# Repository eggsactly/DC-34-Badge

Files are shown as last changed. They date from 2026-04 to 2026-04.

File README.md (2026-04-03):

# About
DC-34 Badge contains the KiCad 6 design files for the Cyber Professionals 
Enthusiast Club (CPEC) DEFCON 34 Badge. 

## Board Features
- 2.2" 320x240 display
- Wifi and Bluetooth LE equiped
- 3 Shitty Add On (SAO) 1.69bis ports equiped with I2C
- Gameboy equivalent buttons
- Rumble pack

## Project Structure
The structure of this repo is organized as such:

| Directory | About |
|:---|:---|
| DC-34-Badge | KiCad 6 Design files |
| digikey-kicad-libraries | Symbol libraries and footprints downloaded from digikey |
| kicad-libraries | git subtree containing expressif design files |

## Running
To view schematics, please run KiCad 6.0.11 or later. Change directory into 
DC-34-Badge and run
```
kicad DC-34-Badge.kicad_pro
```

Please note: please run kicad from the same directory as the .kicad_pro file 
is stored because the fp-lib-table and sym-lib-table use relative paths 
so that this project is portable between computers.

# Associated Repos
Board firmware is developed in this repo: 
[https://github.com/wildcat86/DC34-Mech-Badge](https://github.com/wildcat86/DC34-Mech-Badge)

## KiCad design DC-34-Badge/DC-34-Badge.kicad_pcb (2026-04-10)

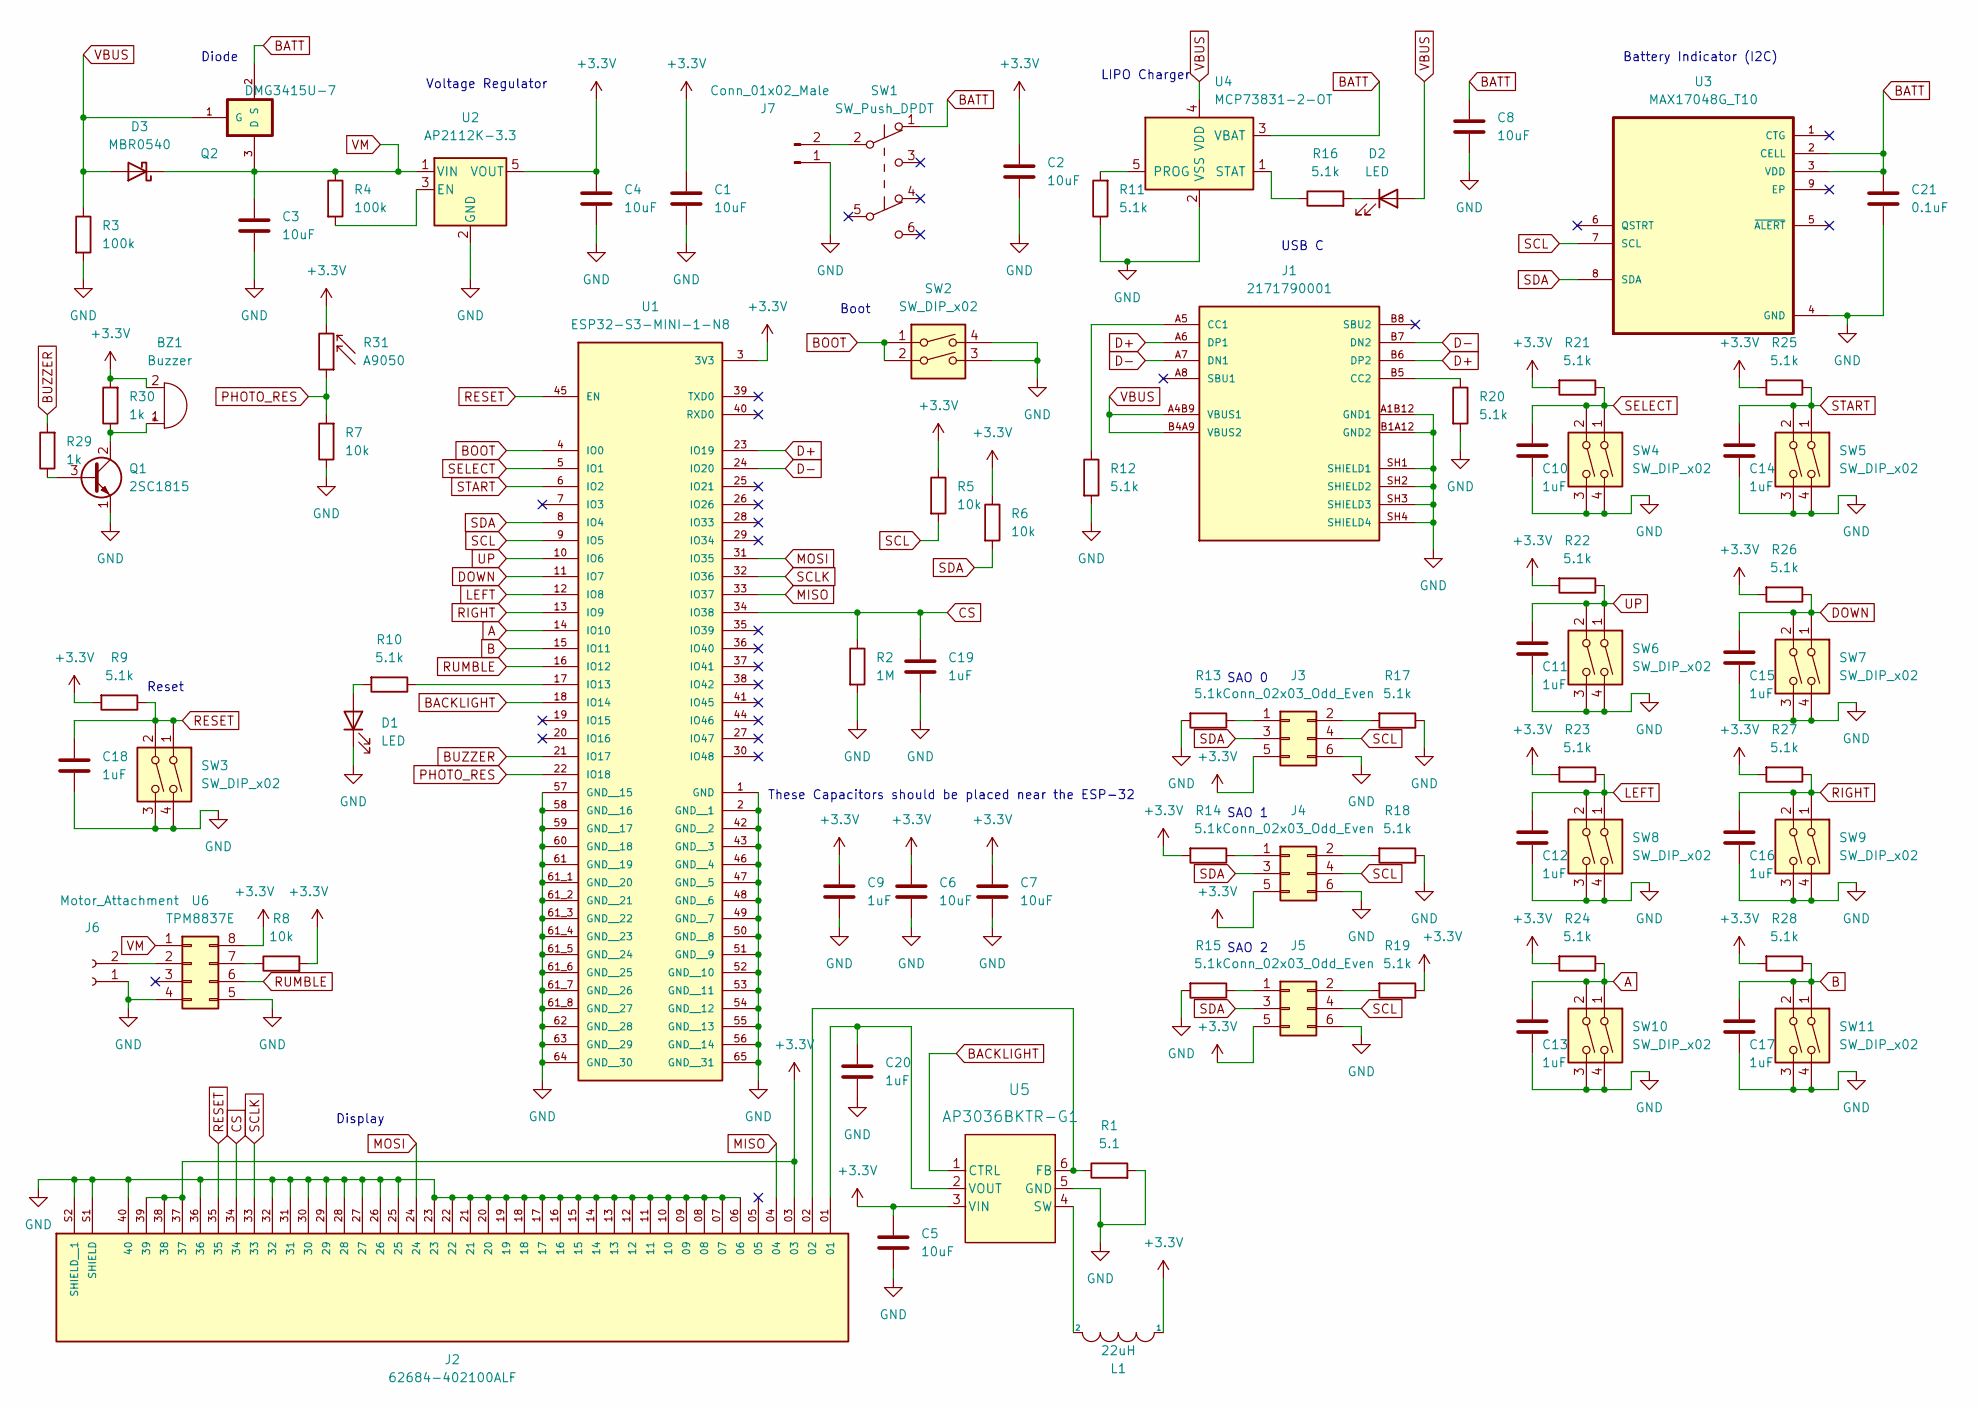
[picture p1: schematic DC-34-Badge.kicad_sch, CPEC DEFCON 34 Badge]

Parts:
BZ1: Buzzer; D_A-405_P5.08mm_Vertical_AnodeUp
C1, C2, C3, C4, C5, C6, C7, C8: 10uF; C_0402_1005Metric
C9, C10, C11, C12, C13, C14, C15, C16, C17, C18, C19, C20: 1uF; C_0402_1005Metric
C21: 0.1uF; C_0402_1005Metric
D1, D2: LED; LED_0201_0603Metric
D3: MBR0540; D_SOD-123
J1: 2171790001; MOLEX_2171790001; PARTREV A1
J2: 62684-402100ALF; AMPHENOL_62684-402100ALF; PARTREV AK
J3, J4, J5: Conn_02x03_Odd_Even; PinHeader_2x03_P2.54mm_Vertical
J6: Motor_Attachment; SolderWire-0.1sqmm_1x02_P3.6mm_D0.4mm_OD1mm
J7: Conn_01x02_Male; JST_XH_B2B-XH-AM_1x02_P2.50mm_Vertical
L1: 22uH; L_1210_3225Metric
Q1: 2SC1815; SOT-23
Q2: DMG3415U-7; SOT95P240X105-3N; MPN DMG3415U-7
R1: 5.1; R_0402_1005Metric
R2: 1M; R_0402_1005Metric
R3, R4: 100k; R_0402_1005Metric
R5, R6, R7, R8: 10k; R_0402_1005Metric
R9, R10, R11, R12, R13, R14, R15, R16, R17, R18, R19, R20, R21, R22, R23, R24, R25, R26, R27, R28: 5.1k; R_0402_1005Metric
R29, R30: 1k; R_0402_1005Metric
R31: A9050; R_LDR_5.0x4.1mm_P3mm_Vertical
SW1: SW_Push_DPDT; SW_CuK_JS202011CQN_DPDT_Straight
SW2, SW3, SW4, SW5, SW6, SW7, SW8, SW9, SW10, SW11: SW_DIP_x02; SW_PUSH_6mm
U1: ESP32-S3-MINI-1-N8; XCVR_ESP32-S3-MINI-1-N8; PARTREV v0.6
U2: AP2112K-3.3; SOT-23-5
U3: MAX17048G_T10; SON50P200X200X80-9N
U4: MCP73831-2-OT; SOT-23-5
U5: AP3036BKTR-G1; SOIC6_AP3036BKTR-G1_DIO
U6: TPM8837E; DFN-8-1EP_2x2mm_P0.5mm_EP0.8x1.6mm

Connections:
+3.3V: BZ1.2 (+), C1.1, C2.1, C4.1, C5.1, C6.1, C7.1, C9.1, J2.03, J2.37, J2.38, J2.39, J3.5, J4.5, J5.5, L1.1, R5.1, R6.1, R8.2, R9.2, R14.2, R19.1, R21.2, R22.2, R23.2, R24.2, R25.2, R26.2, R27.2, R28.2, R30.2, R31.2, U1.3 (3V3), U2.5 (VOUT), U5.3 (VIN), U6.8
A: C13.1, R24.1, SW10.1, SW10.2, U1.14 (IO10)
B: C17.1, R28.1, SW11.1, SW11.2, U1.15 (IO11)
BACKLIGHT: U1.18 (IO14), U5.1 (CTRL)
BATT: C8.1, C21.1, Q2.2 (S), SW1.1 (A), U3.2 (CELL), U3.3 (VDD), U4.3 (VBAT)
BOOT: SW2.1, SW2.2, U1.4 (IO0)
BUZZER: R29.2, U1.21 (IO17)
CS: C19.1, J2.34, R2.1, U1.34 (IO38)
D+: J1.A6 (DP1), J1.B6 (DP2), U1.23 (IO19)
D-: J1.A7 (DN1), J1.B7 (DN2), U1.24 (IO20)
DOWN: C15.1, R26.1, SW7.1, SW7.2, U1.11 (IO7)
GND: C1.2, C2.2, C3.2, C4.2, C5.2, C6.2, C7.2, C8.2, C9.2, C10.2, C11.2, C12.2, C13.2, C14.2, C15.2, C16.2, C17.2, C18.2, C19.2, C20.2, C21.2, D1.1 (K), J1.A1B12 (GND1), J1.B1A12 (GND2), J1.SH1 (SHIELD1), J1.SH2 (SHIELD2), J1.SH3 (SHIELD3), J1.SH4 (SHIELD4), J2.06, J2.07, J2.08, J2.09, J2.10, J2.11, J2.12, J2.13, J2.14, J2.15, J2.16, J2.17, J2.18, J2.19, J2.20, J2.21, J2.22, J2.23, J2.25, J2.26, J2.27, J2.28, J2.29, J2.30, J2.31, J2.32, J2.36, J2.40, J2.S1 (SHIELD), J2.S2 (SHIELD__1), J3.6, J4.6, J5.6, J6.1, J7.1, Q1.1 (E), R1.2, R2.2, R3.2, R7.1, R11.1, R12.2, R13.2, R15.2, R17.1, R18.1, R20.2, SW2.3, SW2.4, SW3.3, SW3.4, SW4.3, SW4.4, SW5.3, SW5.4, SW6.3, SW6.4, SW7.3, SW7.4, SW8.3, SW8.4, SW9.3, SW9.4, SW10.3, SW10.4, SW11.3, SW11.4, U1.1 (GND), U1.2 (GND__1), U1.42 (GND__2), U1.43 (GND__3), U1.46 (GND__4), U1.47 (GND__5), U1.48 (GND__6), U1.49 (GND__7), U1.50 (GND__8), U1.51 (GND__9), U1.52 (GND__10), U1.53 (GND__11), U1.54 (GND__12), U1.55 (GND__13), U1.56 (GND__14), U1.57 (GND__15), U1.58 (GND__16), U1.59 (GND__17), U1.60 (GND__18), U1.61 (GND__19), U1.61_1 (GND__20), U1.61_2 (GND__21), U1.61_3 (GND__22), U1.61_4 (GND__23), U1.61_5 (GND__24), U1.61_6 (GND__25), U1.61_7 (GND__26), U1.61_8 (GND__27), U1.62 (GND__28), U1.63 (GND__29), U1.64 (GND__30), U1.65 (GND__31), U2.2 (GND), U3.4 (GND), U4.2 (VSS), U5.5 (GND), U6.4, U6.5
LEFT: C12.1, R23.1, SW8.1, SW8.2, U1.12 (IO8)
MISO: J2.04, U1.33 (IO37)
MOSI: J2.24, U1.31 (IO35)
unnamed: BZ1.1 (-), Q1.2 (C), R30.1
unnamed: C20.1, J2.01, U5.2 (VOUT)
unnamed: D1.2 (A), R10.2
unnamed: D2.1 (K), R16.2
unnamed: J1.A5 (CC1), R12.1
unnamed: J1.B5 (CC2), R20.1
unnamed: J2.02, R1.1, U5.6 (FB)
unnamed: J3.1, R13.1
unnamed: J3.2, R17.2
unnamed: J4.1, R14.1
unnamed: J4.2, R18.2
unnamed: J5.1, R15.1
unnamed: J5.2, R19.2
unnamed: J6.2, U6.2
unnamed: J7.2, SW1.2 (B)
unnamed: L1.2, U5.4 (SW)
unnamed: Q1.3 (B), R29.1
unnamed: R4.2, U2.3 (EN)
unnamed: R8.1, U6.7
unnamed: R10.1, U1.17 (IO13)
unnamed: R11.2, U4.5 (PROG)
unnamed: R16.1, U4.1 (STAT)
PHOTO_RES: R7.2, R31.1, U1.22 (IO18)
RESET: C18.1, J2.35, R9.1, SW3.1, SW3.2, U1.45 (EN)
RIGHT: C16.1, R27.1, SW9.1, SW9.2, U1.13 (IO9)
RUMBLE: U1.16 (IO12), U6.6
SCL: J3.4, J4.4, J5.4, R5.2, U1.9 (IO5), U3.7 (SCL)
SCLK: J2.33, U1.32 (IO36)
SDA: J3.3, J4.3, J5.3, R6.2, U1.8 (IO4), U3.8 (SDA)
SELECT: C10.1, R21.1, SW4.1, SW4.2, U1.5 (IO1)
START: C14.1, R25.1, SW5.1, SW5.2, U1.6 (IO2)
UP: C11.1, R22.1, SW6.1, SW6.2, U1.10 (IO6)
VBUS: D2.2 (A), D3.2 (A), J1.A4B9 (VBUS1), J1.B4A9 (VBUS2), Q2.1 (G), R3.1, U4.4 (VDD)
VM: C3.1, D3.1 (K), Q2.3 (D), R4.1, U2.1 (VIN), U6.1

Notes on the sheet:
Voltage Regulator
Diode
Battery Indicator (I2C)
SAO 2
SAO 1
Display
USB C
Boot
These Capacitors should be placed near the ESP-32
LIPO Charger
SAO 0
Reset

Board: 2 copper layers, 83 parts (2 on the bottom side), 49 nets, no tracks yet.

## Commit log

2026-03-24 Initial commit.
    [DC-34-Badge.kicad_pcb, DC-34-Badge.kicad_sch]
2026-03-25 Implemented Power System
    Implemented power system circuit in schematic.
    [DC-34-Badge.kicad_sch]
2026-03-26 Added USB
    USB Bus added to design.
    [DC-34-Badge.kicad_sch]
2026-03-27 Completed Power System
    Board design will power up.
    [DC-34-Badge.kicad_sch]
2026-03-28 Base Design Complete
    Full duplication of adafruit design.
    [DC-34-Badge.kicad_sch]
2026-03-28 Added Schematic Description
    Added title, date and company.
2026-03-28 Added ZIF Connector
    Added ZIF connector symbol and footprint.
    [DC-34-Badge.kicad_sch]
2026-03-28 Updated gitignore
    Added _autosave-DC-34-Badge.kicad_sch file to .gitignore file.
2026-03-28 Buttons and Screen Added
    Added buttons and screen and hooked up to design.
    [DC-34-Badge.kicad_sch]
2026-03-28 Added Rumble
    Added H-Bridge to enable motor control from ESP-32.
    [DC-34-Badge.kicad_sch]
2026-04-02 Added 40-pin ZIF connector.
2026-04-03 Added libraries for diode for display circuit.
2026-04-03 Added display circuit, buzzer circuit, and rearranged componets.
    [DC-34-Badge.kicad_sch]
2026-04-03 Added labels for resistors and capacitors.
    [DC-34-Badge.kicad_sch]
2026-04-03 April 3 2026 Meeting
    What was worked on in the Friday collaboration meeting.
    [DC-34-Badge.kicad_pcb, DC-34-Badge.kicad_sch]
2026-04-03 Added No-Connects to Schematic
    Added no-connects to the schematic to address design rule checker findings.
    [DC-34-Badge.kicad_sch]
2026-04-04 Fixed date so that it does not cause issues with Windows kicad.
2026-04-04 Revert "Fixed date so that it does not cause issues with Windows kicad."
    This reverts commit c27fbf2cff545e1d774a93f725a7cd52623fee8b.
2026-04-04 Revert "Reverted the KiCad version from 20211014 to 20220914 (#93)"
    This reverts commit 2f3be4bc595e27d61f933b73df66d1e55d531cf2.
2026-04-04 Added digikey ESP-32-MINI symbol and footprint.
2026-04-04 Updates to the MOLEX footprint.
2026-04-05 Removed design errors from schematic.
    [DC-34-Badge.kicad_sch]
2026-04-05 Updated circuit.
    [DC-34-Badge.kicad_pcb]
2026-04-10 Added footprint libraries and placed componets.
    [DC-34-Badge.kicad_pcb, DC-34-Badge.kicad_sch]
